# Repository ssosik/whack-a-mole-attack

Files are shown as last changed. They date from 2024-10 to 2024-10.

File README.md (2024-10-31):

# whack-a-mole-attack

Project files for a two-player whack-a-mole / button mash game

Original idea by https://github.com/DIYTechBros/ButtonSmack / https://www.youtube.com/watch?v=FXypfZi_UDI

Watch the video (https://www.youtube.com/embed/DrATmFxHTjc)

Use a Teensy 4 to control the game, sending serial messages to a Matrix Portal for driving the graphics on a 32x32 LED Panel.

# Components

- [Teensy 4.1](https://www.pjrc.com/store/teensy41.html)
- [32x32 Adafruit LED Matrix](https://www.adafruit.com/product/2026)
- [Adafruit Matrix Portal S3](https://www.adafruit.com/product/5778)
- XL4015 5A DC Buck Stepdown converter (EBay)
- Batteries (I used 2 21700 batteries in series, but a high-current Lipo should work too)
- 10 60mm dome LED push-buttons
- 2 arcade buttons (player start)

# Parts

- 73x100mm PCB strip board
- spade terminals + quick connectors
- wire
- connectors
- 10K resistors
- M/F barrel connector
- 2x4s
- 1/2 inch finished plywood
- a few 3D printed pieces

# Code

The Teensy is programmed with the Arduino IDE. `WhackAMole.ino` just sets a few things up and then calls `Game::Update()` in the main loop.

`Game.cpp` defines the game states and state transitions, called Update on the players, and sends the Serial messages to the Matrix Portal for each state to drive the display.

`Player.cpp` defines the Player objects and their internal attributes needed to run the game. These attributes include player score, current button and points, input pins, button blink state, button debounce, etc.

`code.py` the CircuitPython code that runs on the Matrix Portal. Listen on the serial port and change the display based on the messages received. This is kinda gross code.

# What worked well

- The Teensy is an awesome little computer. Easy to code, super fast, really stable, and overall just worked all the time
- Using switches in series with 10K resistors in between is an awesome way to read in multiple distinct user inputs while only using one analog pin
- The serial communication between the teensy and the Portal Matrix worked better than I expected and was more than fast enough
- The physical dome buttons held up well to an hour of constant abuse from a whole pack of Cub Scouts
- The LED Matrix itself was nice and bright and refreshed quickly
- The 21700 batteries and buck converter worked great to power the whole thing

# What I would do different

- The LEDs on the dome buttons are not great, just not bright. The DIY TechBros design replaced the built-in resistor to improve brightness, but it didn't make much of an improvement for me.
- The wiring scheme I came up with worked but it was ugly. If I were going to rewire this, I'd use a 4-pin JST connector and ribbon cable per LED button. The inline resistors would need to be moved to the perf board.

# Improvements

- SOUNDS! There is an audio break-out board for the Teensy, adding some sounds would really make the game have an arcade feel
- Better button LEDs. I may try to cram a few WS2812B LEDs into the Dome button housing

# Circuit schematic

TODO

# Table design

I started from the playfield (16x36 inches) and then just built a table from and legs underneath that. I needed to 3d print a few spacer/bushings so that the buttons were snug in the holes I cut (I didn't have a perfectly-sized hole saw). I also 3d printed 21700 battery holders. The battery holders and perf-board are just screwed to the underside with wood screws. The PortalMatrix is piggy-backed onto the back of the LED panel on the 2x10 socket connector. The LED panel is inset into the middle of the playfield; I added supports underneath to keep it flush with the playfield surface. I also added a 3d-printed bezel around the LED panel in an attempt to make it look like a mole hill and to discourage players from bonking it.

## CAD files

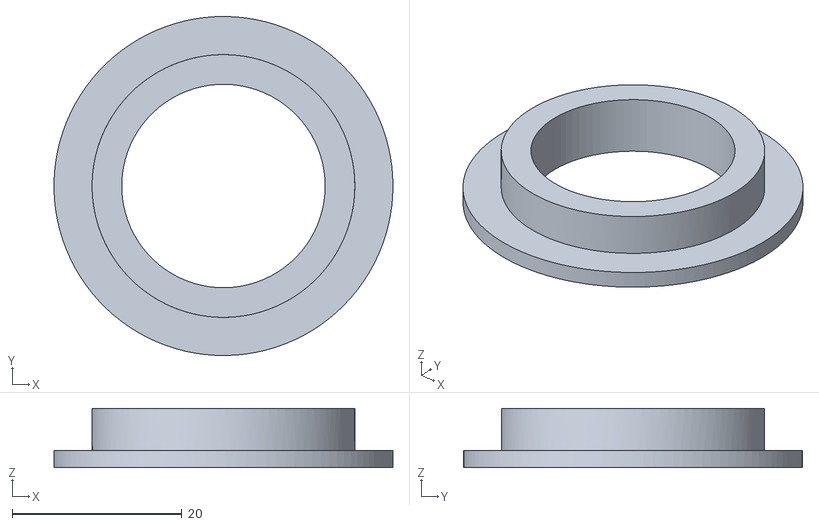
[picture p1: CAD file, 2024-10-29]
whack a mole button hole bushing.stl
40.0 x 40.0 x 7.00

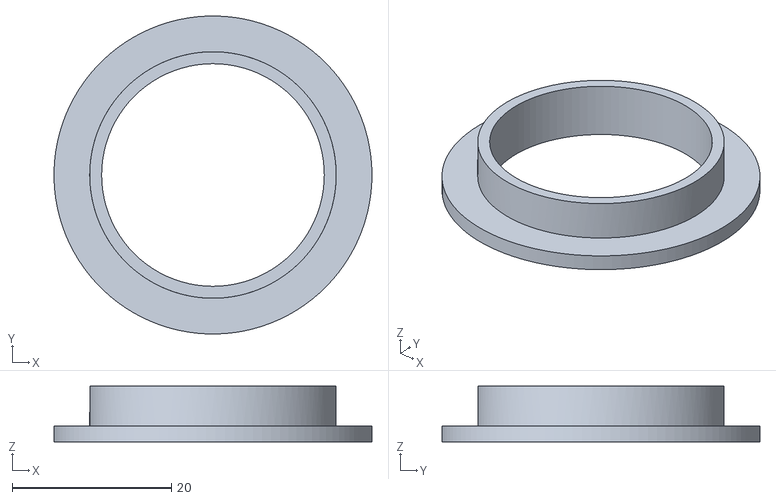
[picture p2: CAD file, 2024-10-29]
whack a mole start button hole bushing.stl
40.0 x 40.0 x 7.00

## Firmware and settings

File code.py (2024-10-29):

from adafruit_display_text.label import Label
import adafruit_display_text.scrolling_label
import adafruit_imageload
import board
import busio
import displayio
import framebufferio
import random
import rgbmatrix
import terminalio
import sys
import time
import re

def p1scroll(line):
    line.y = line.y - 1
    line_width = line.bounding_box[2]
    if line.y < -(len(line.text) * 6):
        line.y = display.width

def p2scroll(line):
    line.y = line.y + 1
    line_width = line.bounding_box[2]
    if line.y >= len(line.text) * 6:
        #line.y = display.width
        line.y = -line_width


displayio.release_displays()
matrix = rgbmatrix.RGBMatrix(
    width=32,
    bit_depth=4,
    rgb_pins=[
        board.MTX_R1,
        board.MTX_G1,
        board.MTX_B1,
        board.MTX_R2,
        board.MTX_G2,
        board.MTX_B2,
    ],
    addr_pins=[board.MTX_ADDRA, board.MTX_ADDRB, board.MTX_ADDRC, board.MTX_ADDRD],
    clock_pin=board.MTX_CLK,
    latch_pin=board.MTX_LAT,
    output_enable_pin=board.MTX_OE,
)
display = framebufferio.FramebufferDisplay(matrix, rotation=0, auto_refresh=False)

splash = displayio.Group()

filename = "running-monty-mole.bmp"
odb = displayio.OnDiskBitmap(filename)
face = displayio.TileGrid(odb, pixel_shader=odb.pixel_shader)
splash.append(face)

class Splash():
    def __init__(self, x):
        self.x = x

    def update(self):
        face.x -= 1
        if face.x < -55:
            face.x = 32

splashObj = Splash(face.x)

player_group = displayio.Group()

p1_label = adafruit_display_text.label.Label(
    text="Whack A Mole Attack      ",
    font=terminalio.FONT,
    color=0x33FF55,
    line_spacing=0.7,
    scale=1,
    label_direction="DWR",
)
p1_label.x = 8
p1_label.y = -4
player_group.append(p1_label)

p2_label = adafruit_display_text.label.Label(
    text="Whack A Mole Attack      ",
    font=terminalio.FONT,
    color=0xFF99FF,
    line_spacing=0.7,
    scale=1,
    label_direction="UPR",
)
p2_label.x = 24
p2_label.y = display.width
player_group.append(p2_label)

do_scroll = True


uart = busio.UART(board.TX, board.RX, baudrate=115200, timeout=0)

patt = re.compile(b"#p1:([0-9]+)#p2:([0-9]+)#loop:([0-9]+)")

try:
    f = open("highscore.txt", "r")
    lines = f.readlines()
    highscore = lines[0]
except:
    highscore = 0

scroll_increment = 125
loop_idx = 0

display.root_group = player_group
showSplash = False
wasShowSplash = False
while True:

    if showSplash:
        wasShowSplash = True
        display.root_group = splash
        splashObj.update()
    if wasShowSplash and not showSplash:
        wasShowSplash = False
        display.root_group = player_group

    display.refresh(minimum_frames_per_second=0)

    data = uart.read(32)

    # We've received some serial data, parse it and figure out what to display
    if data is not None:

        for line in data.splitlines():
            print(line)
            match = patt.search(data)
            if match is not None:
                do_scroll = False

                p1score = int(match.group(1))
                p2score = int(match.group(2))
                loop = int(match.group(3))

                print(
                    "Received Score P1:{} P2:{} Loop:{}".format(p1score, p2score, loop)
                )
                p1_label.text = "{:>6d}".format(p1score)
                p2_label.text = "{:>6d}".format(p2score)

            else:
                if data.startswith(b"#CONREADY"):
                    # Initialize the serial connection between us and the controller
                    uart.write("DSPREADY")
                    showSplash = False
                elif data.startswith(b'#SHOWSPLASH'):
                    do_scroll = False
                    showSplash = True
                elif data.startswith(b'#SHOWPRESSSTART'):
                    do_scroll = True
                    p1_label.text = "Press Start      "
                    p2_label.text = "Press Start      "
                    showSplash = False
                elif data.startswith(b"#SHOWHIGHSCORE"):
                    do_scroll = True
                    p1_label.text = "Highscore: {}      ".format(highscore)
                    p2_label.text = "Highscore: {}      ".format(highscore)
                    showSplash = False
                elif data.startswith(b"#NEWGAME"):
                    do_scroll = True
                    p1_label.text = "New Game       "
                    p2_label.text = "New Game       "
                    showSplash = False
                elif data.startswith(b"#GAMEREADY:READY"):
                    do_scroll = False
                    p1_label.text = " READY "
                    p2_label.text = " READY "
                elif data.startswith(b"#ISP2READY"):
                    do_scroll = True
                    p1_label.text = "Waiting          "
                    showSplash = False
                elif data.startswith(b"#ISP1READY"):
                    do_scroll = True
                    p2_label.text = "Waiting          "
                    showSplash = False
                elif data.startswith(b"#GAMEREADY:SET"):
                    do_scroll = False
                    p1_label.text = "  SET "
                    p2_label.text = "  SET  "
                elif data.startswith(b"#GAMEREADY:GO"):
                    do_scroll = False
                    p1_label.text = "  GO! "
                    p2_label.text = "  GO!  "
                elif data.startswith(b"#PLAYER1WIN"):
                    do_scroll = True
                    score = int(data.split(b":")[1])
                    p2_label.text = "Press Start      "
                    if score > highscore:
                        p1_label.text = "WINNER! NEW HIGHSCORE! {}     ".format(score)
                        highscore = score
                    else:
                        p1_label.text = "YOU WIN {}      ".format(score)
                elif data.startswith(b"#PLAYER2WIN"):
                    do_scroll = True
                    score = int(data.split(b":")[1])
                    p1_label.text = "Press Start      "
                    if score > highscore:
                        p2_label.text = "WINNER! NEW HIGHSCORE! {}     ".format(score)
                        highscore = score
                    else:
                        p2_label.text = "YOU WIN {}      ".format(score)
                elif data.startswith(b"#TIEGAME:"):
                    do_scroll = True
                    score = int(data.split(b":")[1])
                    p1_label.text = "TIE GAME {}      ".format(score)
                    p2_label.text = "TIE GAME {}      ".format(score)

                else:
                    do_scroll = True
                    print("unknown {}".format(data))
                    p1_label.text = "unknown: {}     ".format(data)
                    p2_label.text = "unknown: {}     ".format(data)

    loop_idx += 1
    if do_scroll:
        if loop_idx >= scroll_increment:
            p1scroll(p1_label)
            p2scroll(p2_label)
            loop_idx = 0
    else:
        p1_label.x = 8
        p1_label.y = -4
        p2_label.x = 24
        p2_label.y = 36

    display.refresh()

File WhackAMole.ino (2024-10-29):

#include "Player.h"
#include "Game.h"

const int NUMLED = 5;

// An unconnected "floating" pin to give us some randomness for seeding
const int FLOATINGPIN = 17;
const int P1BUTTONPIN = 27;
const int P2BUTTONPIN = 38;
//                           B   R   W   G   Y
const int P1LEDS[NUMLED] = { 28, 29, 30, 31, 32 };
const int P2LEDS[NUMLED] = { 37, 36, 35, 34, 33 };

// Create Players and Game
Player p1(String("P1"), P1BUTTONPIN, P1LEDS, NUMLED, false);
Player p2(String("P2"), P2BUTTONPIN, P2LEDS, NUMLED, false);
Game state(p1, p2);

void setup() {
  randomSeed(analogRead(FLOATINGPIN));
}

void loop() {
  state.Update();
}
